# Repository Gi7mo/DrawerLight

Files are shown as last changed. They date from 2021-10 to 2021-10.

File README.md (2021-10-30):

**BOM**
|Part NO.  |Qty  |
|--|--|
| LED Extrusion | 1 |
| TCRT5000L Reflective Optical Sensor | 1 |
| 10uF Capacitor | 2 |
| BS170FTA N-P-N Transistor | 1 |
| L4941BDT-TR Stepdown Converter | 1 |
| 90° XH Connector | 2 |
| 47K Resistor | 1 |
| 220 Resistor | 1 |

Buy some [Lumentec led extrusions](https://lumentec.eu/epages/e4360bea-6b9b-4161-a115-a88bb0233b45.sf/de_DE/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)

Order the PCBS at e.g. [JLCPCB](https://jlcpcb.com/) dont forget to add the stencil

Order the parts at e.g. [LCSC](https://www.lcsc.com/) you can upload the BOM to their [uploader](https://www.lcsc.com/bom) and select the "Supplier Part" from the bom as their "LCSC Part Number"

**Assembly**
- Print the mounts
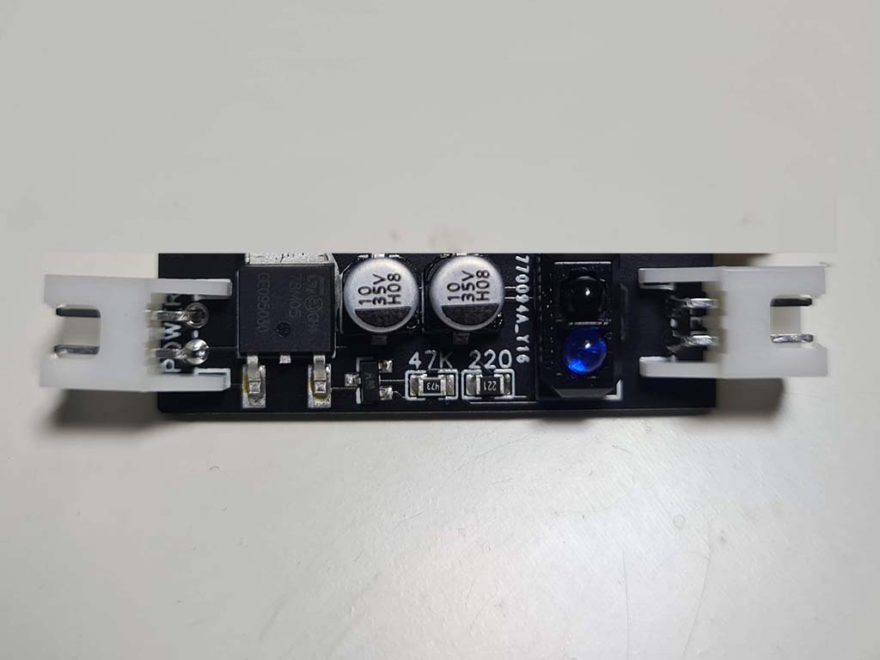
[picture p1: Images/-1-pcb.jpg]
PCB
- 
- Assemble the PCB
- Cut the Extrusions to your desired length
- Lay your led strips into the extrusions
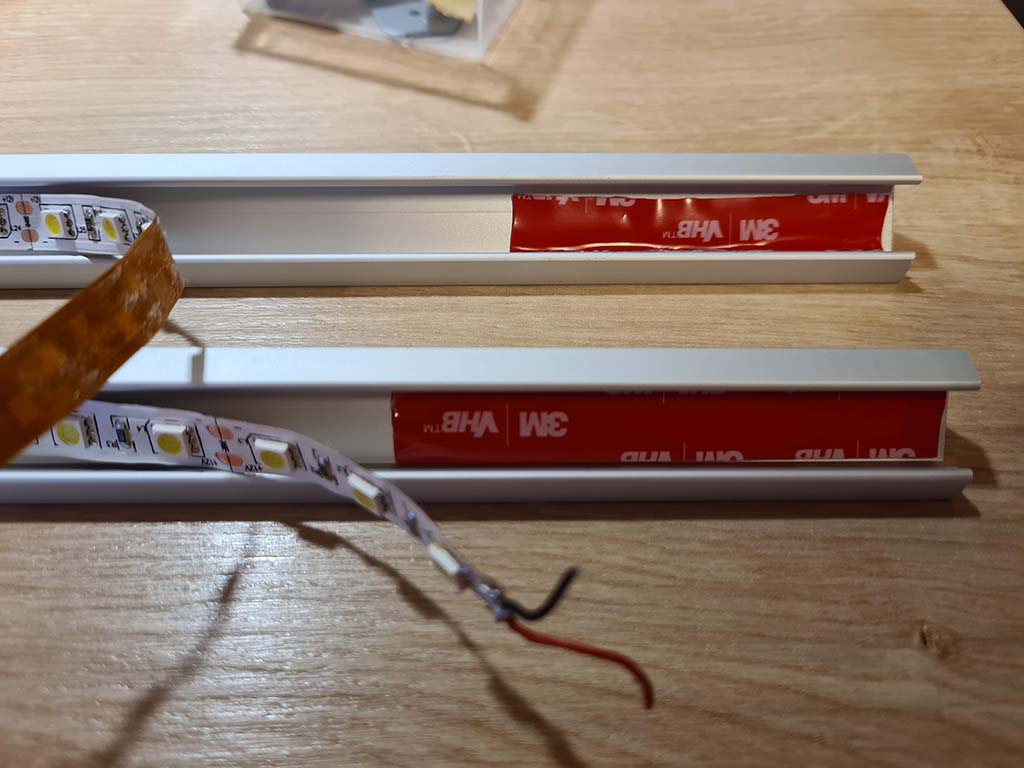
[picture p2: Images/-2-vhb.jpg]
VHB
- 
- Add some vhb to the end of the strip to avoid shorts and stick on your PCB
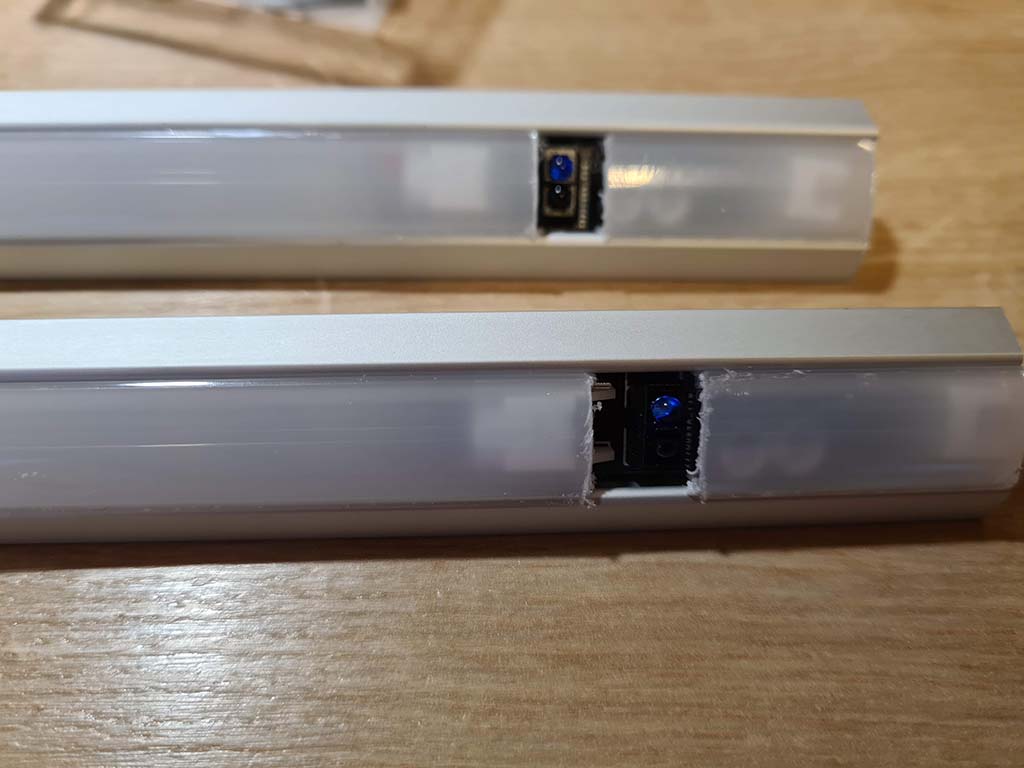
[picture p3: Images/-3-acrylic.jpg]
ACRYLIC
- 
- Cut the acrylics that your TCRT sticks out
- Be sure to add your power cable before you add the mounts, or to it like me and cutout the bridge
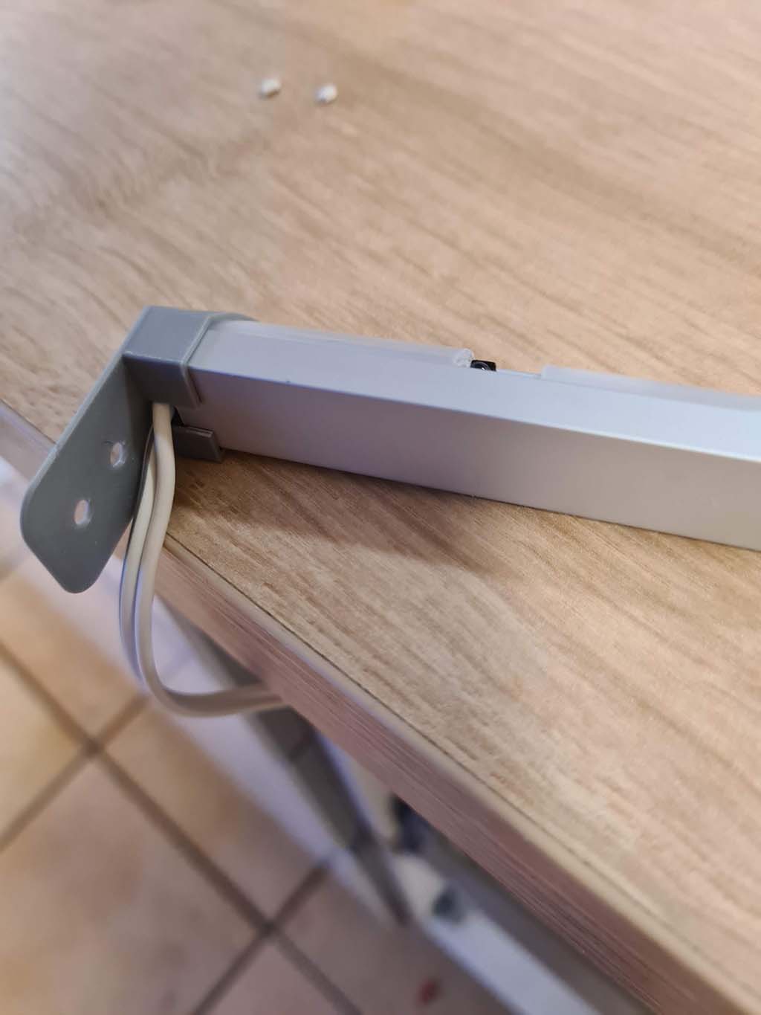
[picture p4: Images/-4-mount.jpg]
MOUNT
- 
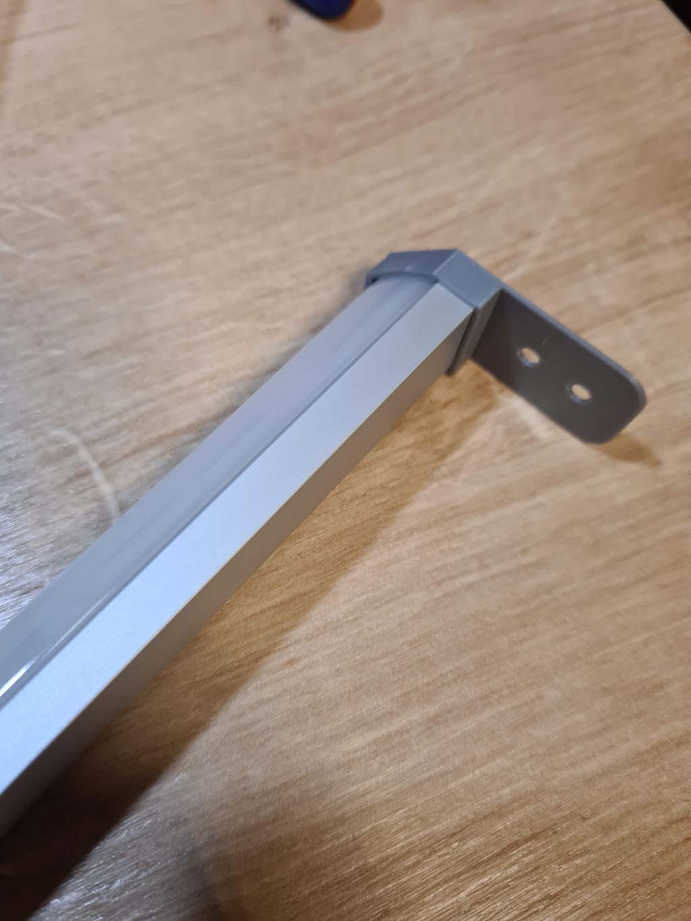
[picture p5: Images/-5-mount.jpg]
MOUNT
- 
- Add the mounts to the extrusions, they fit very tight around the acrylic, i used some pliers to get around it
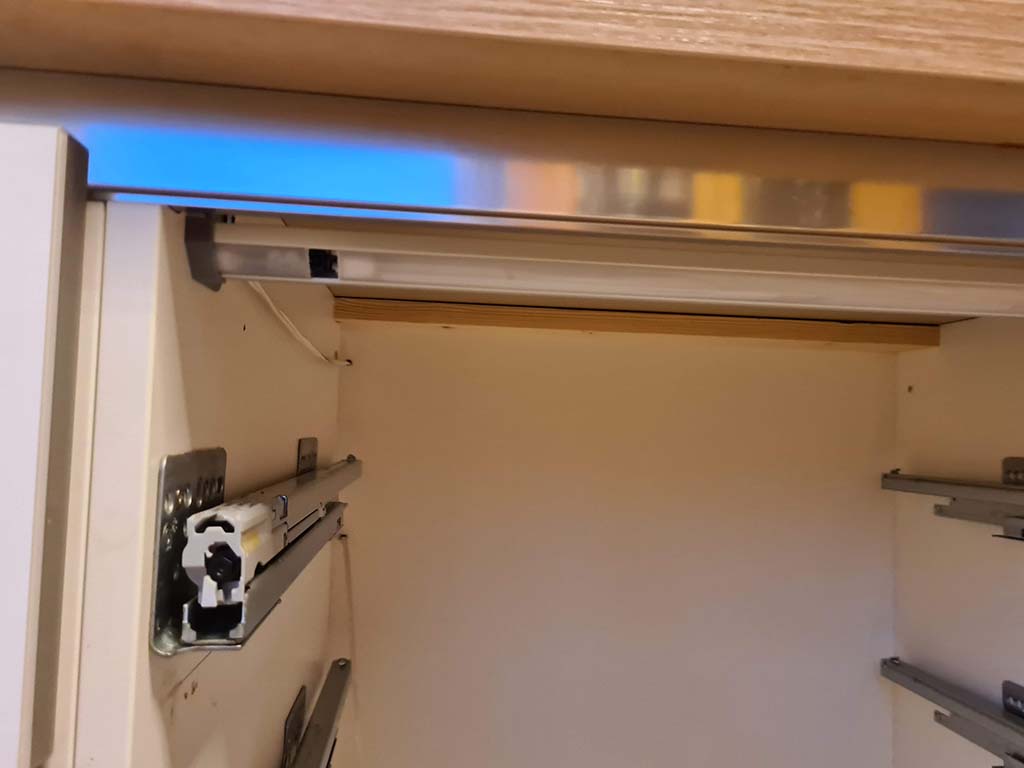
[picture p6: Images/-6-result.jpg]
RESULT
- 
- Mount the lightbars in your drawer, do a testfit as the sensing distance is not this far
- for me it was about 8mm from the drawer front
- ACTION
- it looks so awesome

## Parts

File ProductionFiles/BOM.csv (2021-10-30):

ID | Name | Designator | Footprint | Quantity | Manufacturer Part | Manufacturer | Supplier | Supplier Part | Price
1 | TCRT5000L | CGQ1 | OPTO-TH_TCRT5000L | 1 | TCRT5000L | VISHAY | LCSC | C24085 | 0.811
2 | 10uF | C1,C2 | CAP-SMD_BD5.0-L5.3-W5.3-FD | 2 | HV100M035C055R | CapXon | LCSC | C59943 | 0.039
3 | BS170FTA | Q1 | SOT-23_L2.9-W1.3-P1.90-LS2.4-BR | 1 | BS170FTA | DIODES | LCSC | C151050 | 0.202
4 | L4941BDT-TR | U1 | TO-252-2_L6.6-W6.1-P4.57-LS9.9-BR-CW | 1 | L4941BDT-TR | STMicroelectronics | LCSC | C262889 | 0.933
5 | S2B-XH-A-(LF)(SN) | LED,POWER | CONN-TH_S2B-XH-A-LF-SN | 2 | S2B-XH-A-(LF)(SN) | JST Sales America | LCSC | C157931 | 0.041
6 | 47K | 47K | R0805 | 1 | WR08X473JTL | WALSIN | LCSC | C164001 | 0.003
7 | 220 | 220 | R0805 | 1 | 0805W8J0221T5E | UniOhm | LCSC | C25294 | 0.002

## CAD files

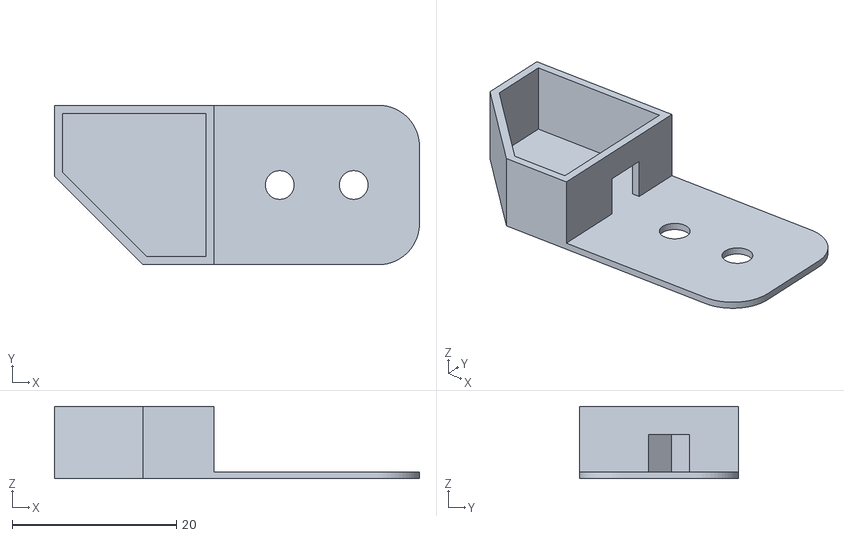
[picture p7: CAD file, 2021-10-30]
Stls/left.stl
44.4 x 19.4 x 8.80

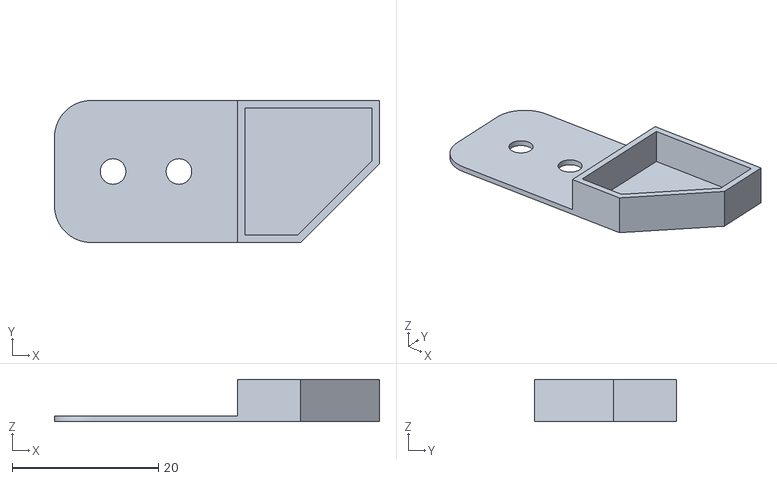
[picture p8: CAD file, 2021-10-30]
Stls/right.stl
44.4 x 19.4 x 5.80
